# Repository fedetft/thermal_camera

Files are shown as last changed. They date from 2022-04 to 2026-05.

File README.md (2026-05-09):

Thermal camera
===============

An open source thermal camera, including firmware, schematic and PCB design.

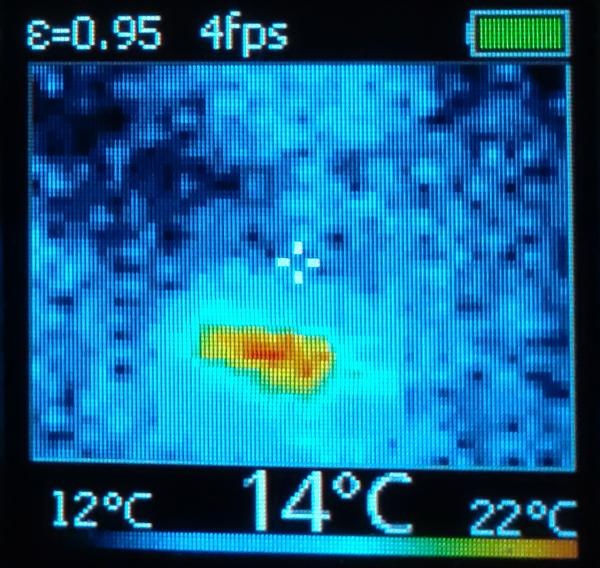
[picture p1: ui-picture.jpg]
UI example

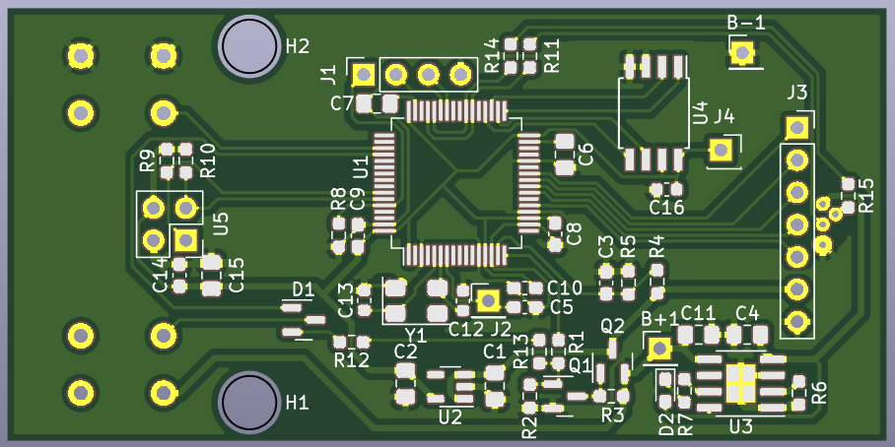
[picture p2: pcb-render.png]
PCB render


How to build
============

This guide assumes you already have a Miosix build environment installed, if not see
[here](https://miosix.org/wiki/index.php?title=Linux_Quick_Start).

```
# Dependencies (should work both on Linux and WSL)
sudo apt install build-essential cmake libboost-all-dev libpng-dev

# Submodules
git submodule init
git submodule update

# Build mxgui code generators for embedding images and fonts
cd mxgui/_tools/code_generators
chmod +x compile_freetype.sh
mkdir build
cd build
cmake ..
make

# Build the thermal camera application
cd ../../../..
make -j`nproc`
```

How to flash
============

Install the dfu-util program on your pc.

Connect the USB cable between the PC an thermal camera, while the camera is off.

Use a jumper wire to connect BOOT0 (on the 4 pin header) to +3.3V (a convenient
spot is a capacitor next to the voltage regulator). You can just hold the wire
with your hands.

While the jumper is in place, press and hold the power on button of the camera.

You can disconnect the jumper but keep holding the power button. If you release
the power button, you need to reconnect the jumper and start again.

On the PC, run the command while holding the power button.
```
dfu-util -a 0 -s 0x08000000:leave -D main.bin
```

You should see a progress bar on the PC, keep holding the power button till the
progress bar reaches 100%.

Release the power button, and disconnect the USB cable.

Power on the camera and enjoy the new firmware. You cannot brick the camera,
if something goes wrong you can repeat the operation.

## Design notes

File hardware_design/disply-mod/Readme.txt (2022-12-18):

Modding the OLED display
========================

The OLED display has a single VCC line that is connected to both
- the display controller chip, maximum voltage 3.6V
- the DC-DC step-up voltage regulator to produce +12V for the OLED panel,
  the DC-DC chip has a maximum input voltage of 5.5V

To optimize the battery life of the thermal camera, those two supply lines have
been split, so as to power the display controller with 3.3V, but connect the
DC-DC directly to the lithium battey voltage (3.5..4.2V).

NOTE: the display mod is mandatory, soldering an unmodded display will drive
the display controller with 4.2V and permanently damage it.

How to mod the OLED display
===========================

See display_mod.jpg

With a knife carefully cut the shown trace to separate the logic power trace
from the DC-DC power trace. Confirm with a multimeter that the trace is cut and
not accidentally shorted to ground (the trace immediately above and below is
ground).

With the same knife or similar tool carefully scrape the soldermask to the
left side of the trace, the one connecting to the display controller chip,
and solder a short piece of flexible copper wire.

Finally, when soldering the display to the thermal camera board, there is a
one-pin connector, J4 where the flexible wire going to the display controller
needs to be soldeered.

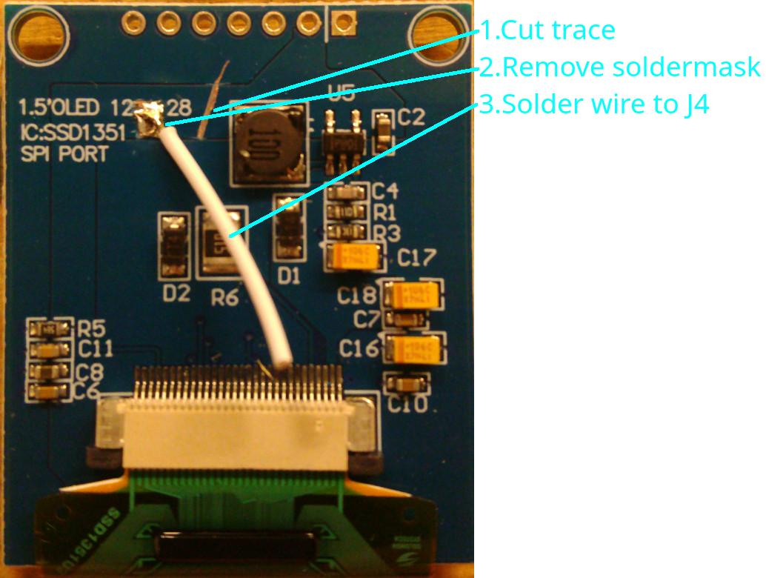
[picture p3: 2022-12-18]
hardware_design/disply-mod/display_mod.jpg

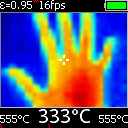
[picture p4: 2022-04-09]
ui-mockup-main-screen.png

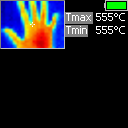
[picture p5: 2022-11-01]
ui-mockup-menu-screen.png

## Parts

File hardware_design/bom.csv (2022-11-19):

Qty | Reference(s) | Value | Footprint
5 | R1, R3, R6, R9, R10 | 3k3 | Resistor_SMD:R_0603_1608Metric
4 | R2, R4, R5, R8 | 220k | Resistor_SMD:R_0603_1608Metric
1 | R7 | 470 | Resistor_SMD:R_0603_1608Metric
5 | R11, R12, R13, R14, R15 | 0 | Resistor_SMD:R_0603_1608Metric
5 | C1, C2, C4, C11, C15 | 1u | Capacitor_SMD:C_0805_2012Metric
7 | C3, C5, C8, C9, C10, C14, C16 | 100n | Capacitor_SMD:C_0603_1608Metric
2 | C6, C7 | 2u2 | Capacitor_SMD:C_0805_2012Metric
2 | C12, C13 | 10p | Capacitor_SMD:C_0603_1608Metric
1 | D1 | BAT54A | SOT-23
1 | D2 | LED | LED_SMD:LED_0603_1608Metric
1 | J1 | 4 pin serial/programming connector | Connector_PinSocket_2.54mm
0 | J2 | Do not fit
1 | J3, J4 | ER_OLEDM015 OLED color 128x128 | https://www.ebay.com/itm/401236987473 NOTE: requires modding to separate DCDC power from logic power, soldering an unmodded display will damage it!
1 | J5 | USB_B_Mini | TE Connectivity:2172034-1
1 | Q1 | AP2312 / SI2312 | SOT-23
1 | Q2 | AP2311 / SI2311 | SOT-23
2 | SW1, SW2 | 1-1825910-4 | SW_PUSH_6mm TE connectivity:1-1825910-4 Mouser:506-1-1825910-4
1 | U1 | STM32F205RC | LQFP-64
1 | U2 | LP2981-3.3 | SOT-23-5
1 | U3 | TP4056 | SOIC-8-1EP
1 | U4 | W25Q64 | SOIC-8W
1 | U5 | MLX90640-BAB | NOTE: Requires bending pins for right angle mount
1 | Y1 | 8MHz | ABRACON ABM3B-8.000MHZ-10-1-U-T
1 | B+1, B-1 | LiPo battery 1Ah | https://www.ebay.com/itm/123867825568

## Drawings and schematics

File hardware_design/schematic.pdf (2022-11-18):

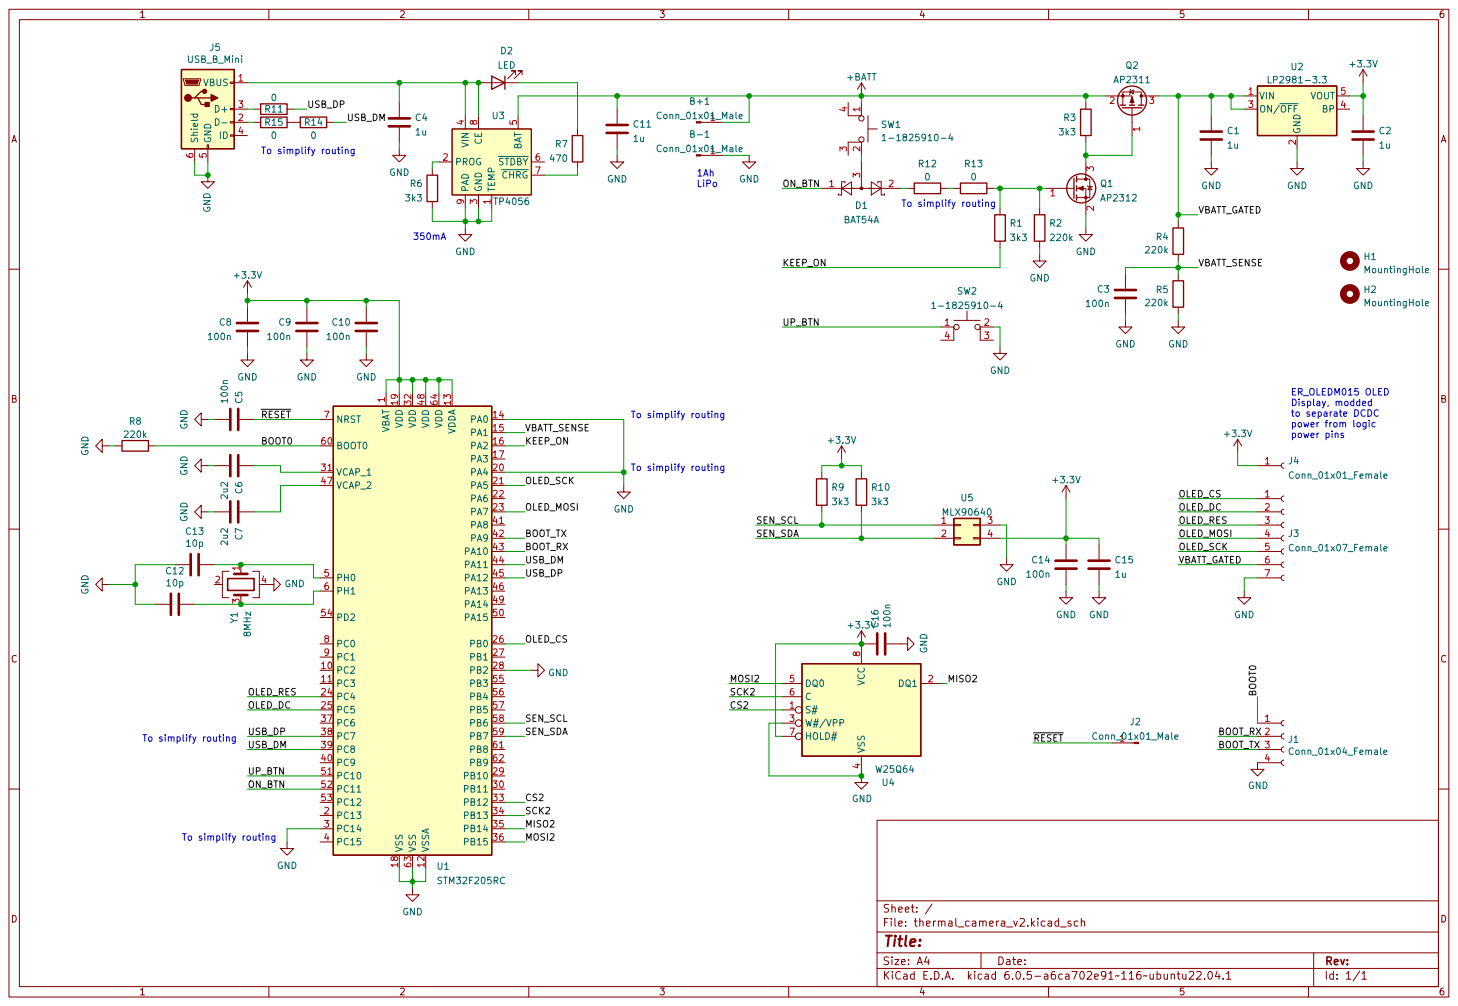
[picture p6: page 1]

2 ON/~{OFF} 3 BP 4 VOUT 5 U2
LP2981-3.3 GND

1 PC2 10 PC3 11 VSSA 12 VDDA 13 PA0 14 PA1 15 PA2 16 PA3 17 VSS 18 VDD 19 PC13 2 PA4 20 PA5 21 PA6 22 PA7 23 PC4 24 PC5 25 PB0 26 PB1 27 PB2 28 PB10 29 PC14 3 PB11 30 VCAP_1 31 VDD 32 PB12 33 PB13 34 PB14 35 PB15 36 PC6 37 PC7 38 PC8 39 PC15 4 PC9 40 PA8 41 PA9 42 PA10 43 PA11 44 PA12 45 PA13 46 VCAP_2 47 VDD 48 PA14 49 PH0 5 PA15 50 PC10 51 PC11 52 PC12 53 PD2 54 PB3 55 PB4 56 PB5 57 PB6 58 PB7 59 PH1 6 BOOT0 60 PB8 61 PB9 62 VSS 63 VDD 64 NRST 7 PC0 8 PC1 9 U1STM32F205RC

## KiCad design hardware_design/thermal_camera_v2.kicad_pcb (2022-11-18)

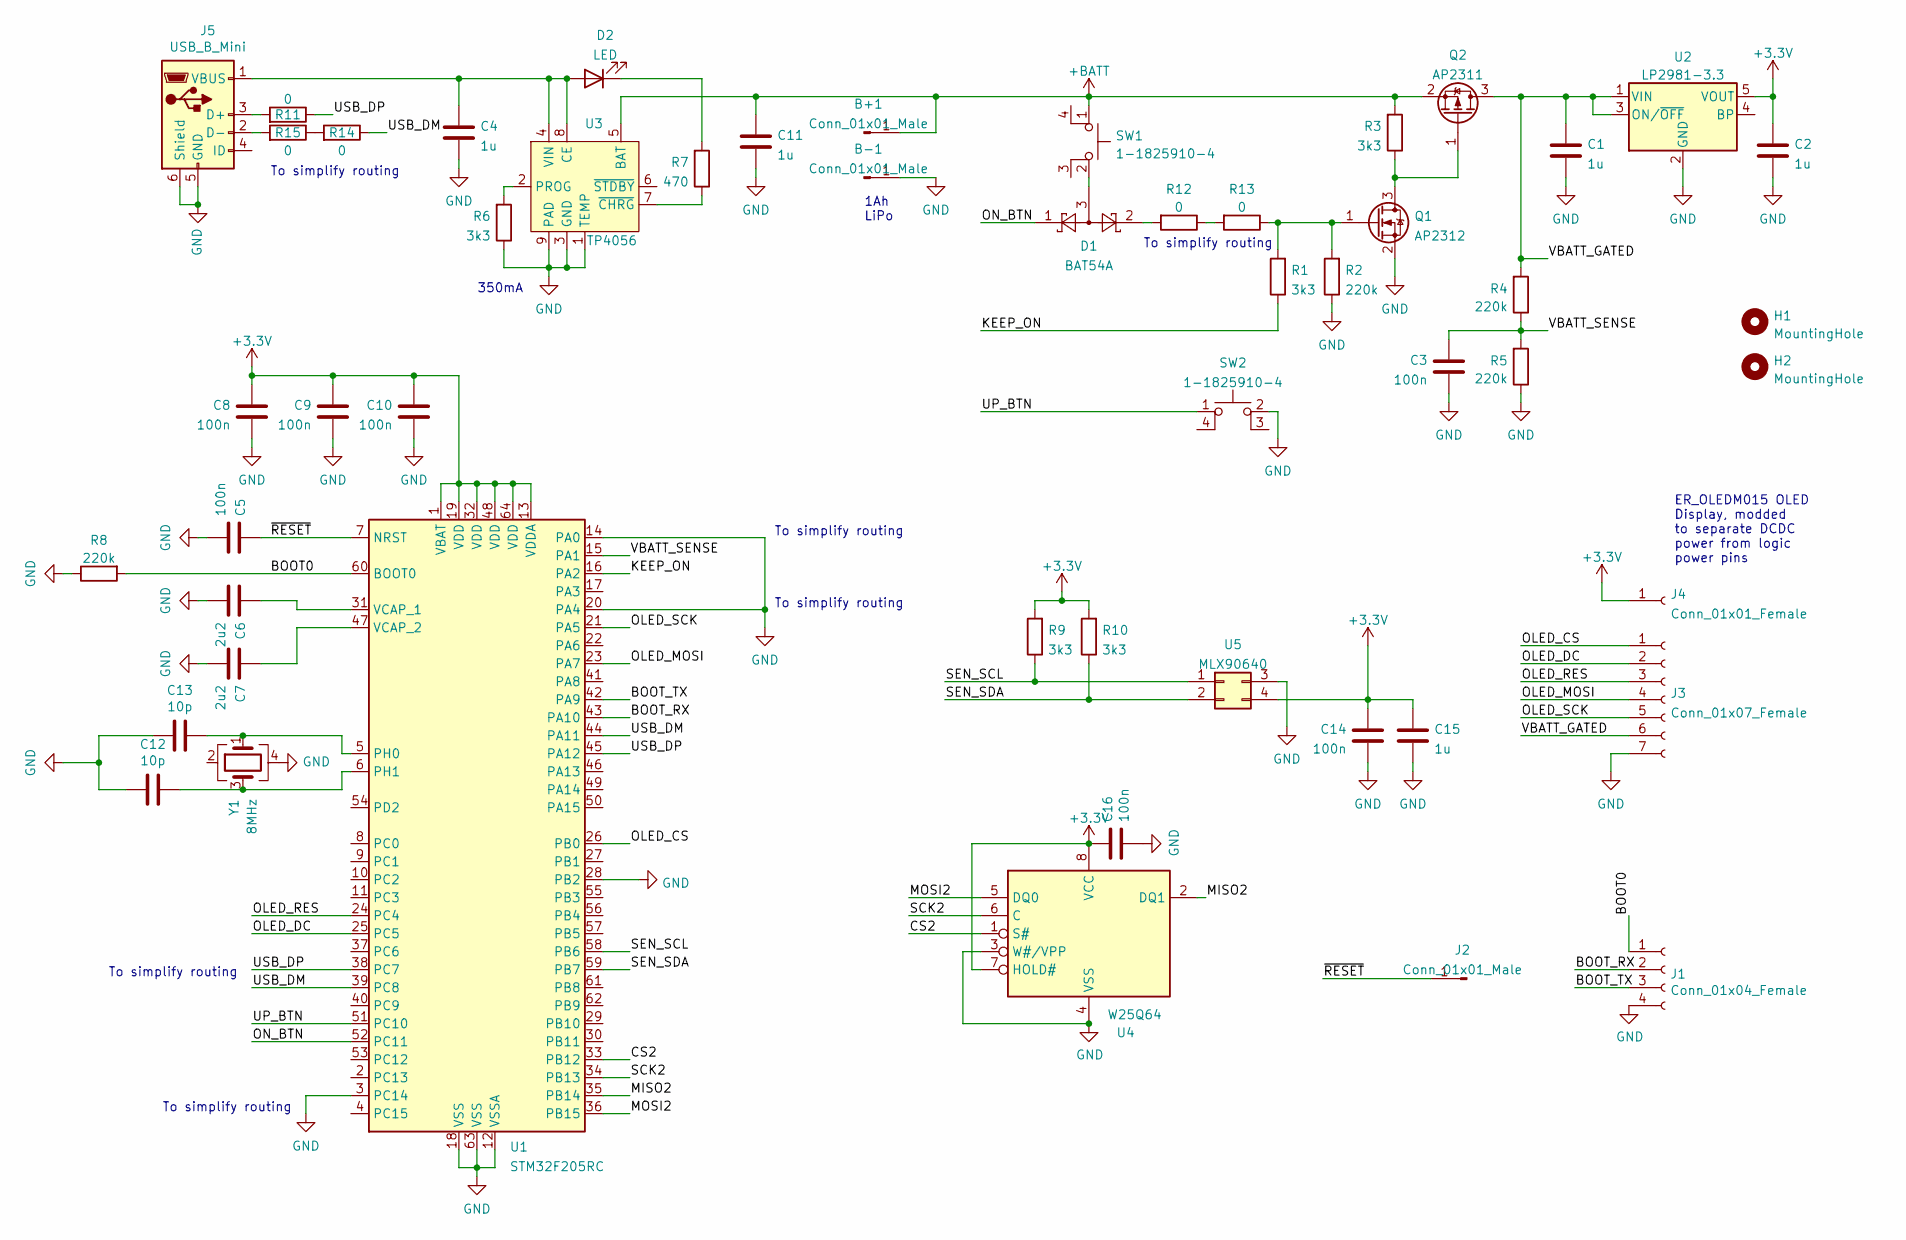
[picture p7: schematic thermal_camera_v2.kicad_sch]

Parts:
B+1: Conn_01x01_Male; PinHeader_1x01_P2.54mm_Vertical
B-1: Conn_01x01_Male; PinHeader_1x01_P2.54mm_Vertical
C1, C2, C4, C11, C15: 1u; C_0805_2012Metric_Pad1.18x1.45mm_HandSolder
C3, C5, C8, C9, C10, C14: 100n; C_0603_1608Metric_Pad1.08x0.95mm_HandSolder
C6, C7: 2u2; C_0805_2012Metric_Pad1.18x1.45mm_HandSolder
C12, C13: 10p; C_0603_1608Metric
C16: 100n; C_0603_1608Metric
D1: BAT54A; SOT-23
D2: LED; LED_0603_1608Metric_Pad1.05x0.95mm_HandSolder
H1, H2: MountingHole; MountingHole_2.1mm
J1: Conn_01x04_Female; PinSocket_1x04_P2.54mm_Vertical
J2: Conn_01x01_Male; PinHeader_1x01_P2.54mm_Vertical
J3: Conn_01x07_Female; PinSocket_1x07_P2.54mm_Vertical
J4: Conn_01x01_Female; PinSocket_1x01_P2.54mm_Vertical
J5: USB_B_Mini; USB_mini_china_unknown
Q1: AP2312; SOT-23
Q2: AP2311; SOT-23
R1, R3, R6, R9, R10: 3k3; R_0603_1608Metric_Pad0.98x0.95mm_HandSolder
R2, R4, R5, R8: 220k; R_0603_1608Metric_Pad0.98x0.95mm_HandSolder
R7: 470; R_0603_1608Metric_Pad0.98x0.95mm_HandSolder
R11, R12, R13, R14, R15: 0; R_0603_1608Metric_Pad0.98x0.95mm_HandSolder
SW1, SW2: 1-1825910-4; SW_PUSH_6mm
U1: STM32F205RC; LQFP-64_10x10mm_P0.5mm
U2: LP2981-3.3; SOT-23-5
U3: TP4056; SOIC-8-1EP_3.9x4.9mm_P1.27mm_EP2.29x3mm
U4: W25Q64; SOIC-8W_5.3x5.3mm_P1.27mm
U5: MLX90640; PinSocket_2x02_P2.54mm_Vertical
Y1: 8MHz; Crystal_SMD_5032-4Pin_5.0x3.2mm

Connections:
+3V3: C2.1, C8.2, C9.2, C10.2, C14.2, C15.1, C16.1, J4.1, R9.2, R10.2, U1.1 (VBAT), U1.13 (VDDA), U1.19 (VDD), U1.32 (VDD), U1.48 (VDD), U1.64 (VDD), U2.5 (VOUT), U4.7 (HOLD#), U4.8 (VCC), U5.4
+BATT: B+1.1, C11.1, Q2.2 (S), R3.2, SW1.1, U3.5 (BAT)
/BOOT0: J1.1, R8.2, U1.60 (BOOT0)
/BOOT_RX: J1.2, U1.43 (PA10)
/BOOT_TX: J1.3, U1.42 (PA9)
/CS2: U1.33 (PB12), U4.1 (S#)
/KEEP_ON: R1.1, U1.16 (PA2)
/MISO2: U1.35 (PB14), U4.2 (DQ1)
/MOSI2: U1.36 (PB15), U4.5 (DQ0)
/OLED_CS: J3.1, U1.26 (PB0)
/OLED_DC: J3.2, U1.25 (PC5)
/OLED_MOSI: J3.4, U1.23 (PA7)
/OLED_RES: J3.3, U1.24 (PC4)
/OLED_SCK: J3.5, U1.21 (PA5)
/ON_BTN: D1.1, U1.52 (PC11)
/SCK2: U1.34 (PB13), U4.6 (C)
/SEN_SCL: R9.1, U1.58 (PB6), U5.1
/SEN_SDA: R10.1, U1.59 (PB7), U5.2
/UP_BTN: SW2.1, U1.51 (PC10)
/USB_DM: R14.1, U1.39 (PC8), U1.44 (PA11)
/USB_DP: R11.1, U1.38 (PC7), U1.45 (PA12)
/VBATT_GATED: C1.1, J3.6, Q2.3 (D), R4.2, U2.1 (VIN), U2.3 (ON/~OFF)
/VBATT_SENSE: C3.2, R4.1, R5.2, U1.15 (PA1)
/~RESET: C5.2, J2.1, U1.7 (NRST)
GND: B-1.1, C1.2, C2.2, C3.1, C4.2, C5.1, C6.2, C7.2, C8.1, C9.1, C10.1, C11.2, C12.2, C13.2, C14.1, C15.2, C16.2, J1.4, J3.7, J5.5 (GND), J5.6 (Shield), Q1.2 (S), R2.1, R5.1, R6.1, R8.1, SW2.2, U1.3 (PC14), U1.12 (VSSA), U1.14 (PA0), U1.18 (VSS), U1.20 (PA4), U1.28 (PB2), U1.63 (VSS), U2.2 (GND), U3.1 (TEMP), U3.3 (GND), U3.9 (PAD), U4.3 (W#/VPP), U4.4 (VSS), U5.3, Y1.4
unnamed: C4.1, D2.2 (A), J5.1 (VBUS), U3.4 (VIN), U3.8 (CE)
unnamed: C6.1, U1.31 (VCAP_1)
unnamed: C7.1, U1.47 (VCAP_2)
unnamed: C12.1, U1.6 (PH1), Y1.3
unnamed: C13.1, U1.5 (PH0), Y1.1
unnamed: D1.2, R12.2
unnamed: D1.3, SW1.2
unnamed: D2.1 (K), R7.2
unnamed: J5.2 (D-), R15.2
unnamed: J5.3 (D+), R11.2
unnamed: Q1.1 (G), R1.2, R2.2, R13.1
unnamed: Q1.3 (D), Q2.1 (G), R3.1
unnamed: R6.2, U3.2 (PROG)
unnamed: R7.1, U3.7 (~CHRG)
unnamed: R12.1, R13.2
unnamed: R14.2, R15.1

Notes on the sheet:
To simplify routing
ER_OLEDM015 OLED Display, modded to separate DCDC power from logic power pins
350mA
1Ah LiPo

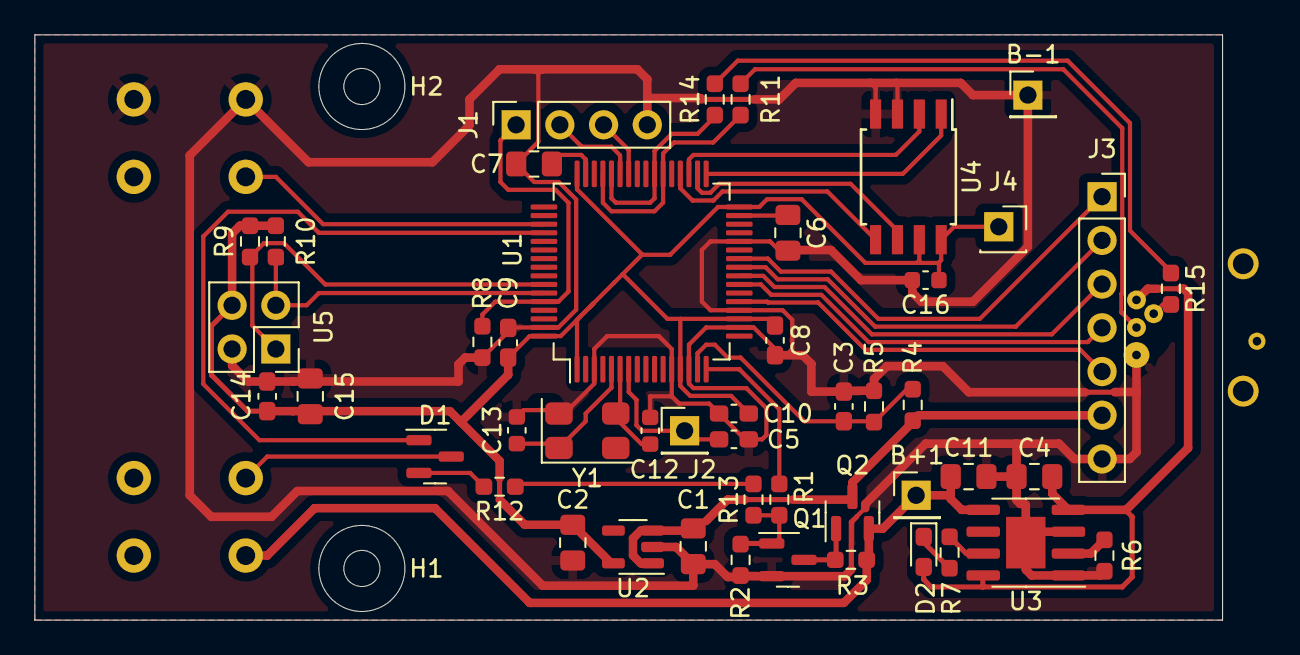
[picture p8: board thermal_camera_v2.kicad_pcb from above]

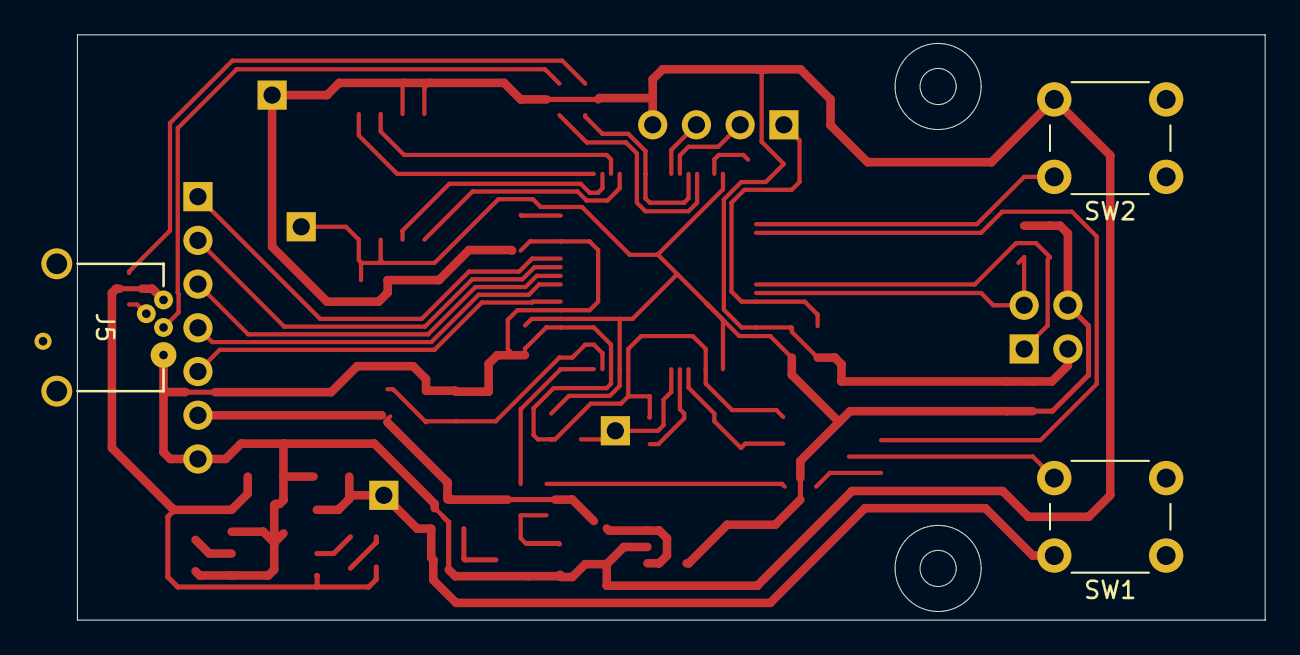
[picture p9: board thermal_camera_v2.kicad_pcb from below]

Board: 2 copper layers, 69.0 x 34.0 mm, 52 parts (3 on the bottom side), 41 nets.

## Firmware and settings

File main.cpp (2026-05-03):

/***************************************************************************
 *   Copyright (C) 2022 by Terraneo Federico                               *
 *                                                                         *
 *   This program is free software; you can redistribute it and/or modify  *
 *   it under the terms of the GNU General Public License as published by  *
 *   the Free Software Foundation; either version 2 of the License, or     *
 *   (at your option) any later version.                                   *
 *                                                                         *
 *   This program is distributed in the hope that it will be useful,       *
 *   but WITHOUT ANY WARRANTY; without even the implied warranty of        *
 *   MERCHANTABILITY or FITNESS FOR A PARTICULAR PURPOSE.  See the         *
 *   GNU General Public License for more details.                          *
 *                                                                         *
 *   As a special exception, if other files instantiate templates or use   *
 *   macros or inline functions from this file, or you compile this file   *
 *   and link it with other works to produce a work based on this file,    *
 *   this file does not by itself cause the resulting work to be covered   *
 *   by the GNU General Public License. However the source code for this   *
 *   file must still be made available in accordance with the GNU General  *
 *   Public License. This exception does not invalidate any other reasons  *
 *   why a work based on this file might be covered by the GNU General     *
 *   Public License.                                                       *
 *                                                                         *
 *   You should have received a copy of the GNU General Public License     *
 *   along with this program; if not, see <http://www.gnu.org/licenses/>   *
 ***************************************************************************/

#include <cstdio>
#include "miosix.h"
#include <drivers/misc.h>
#include <application.h>
#include <mxgui/display.h>
#include <drivers/display_er_oledm015.h>

using namespace std;
using namespace mxgui;
using namespace miosix;

namespace mxgui {
void registerDisplayHook(DisplayManager& dm)
{
    dm.registerDisplay(new DisplayErOledm015);
}
} //namespace mxgui

#ifdef WITH_CPU_TIME_COUNTER
void *profilerMain(void *)
{
    CPUProfiler::thread(5000000000LL);
    return nullptr;
}
#endif

int main()
{
    initializeBoard();
    
    #ifdef WITH_CPU_TIME_COUNTER
    Thread *profiler = Thread::create(profilerMain, 2048U, Priority(0), nullptr);
    #endif

    auto& display=DisplayManager::instance().getDisplay();
    
    try {
        Application app(display);
        app.run();
    } catch(exception& e) {
        iprintf("exception: %s\n",e.what());
    }
    
    display.turnOff();
    #ifdef WITH_CPU_TIME_COUNTER
    profiler->terminate();
    profiler->join();
    #endif
    shutdownBoard();
}

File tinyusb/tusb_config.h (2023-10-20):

#ifndef _TUSB_CONFIG_H_
#define _TUSB_CONFIG_H_

#ifdef __cplusplus
 extern "C" {
#endif

//--------------------------------------------------------------------+
// Board Specific Configuration
//--------------------------------------------------------------------+

// RHPort number used for device can be defined by board.mk, default to port 0
#ifndef BOARD_TUD_RHPORT
#define BOARD_TUD_RHPORT      0
#endif

// RHPort max operational speed can defined by board.mk
#ifndef BOARD_TUD_MAX_SPEED
#define BOARD_TUD_MAX_SPEED   OPT_MODE_DEFAULT_SPEED
#endif

//--------------------------------------------------------------------
// Common Configuration
//--------------------------------------------------------------------

// defined by compiler flags for flexibility
#ifndef CFG_TUSB_MCU
#define CFG_TUSB_MCU          OPT_MCU_STM32F2
#endif

#ifndef CFG_TUSB_OS
#define CFG_TUSB_OS           OPT_OS_CUSTOM
#endif

#ifndef CFG_TUSB_DEBUG
#define CFG_TUSB_DEBUG        1
#endif

// Enable Device stack
#define CFG_TUD_ENABLED       1

// Default is max speed that hardware controller could support with on-chip PHY
#define CFG_TUD_MAX_SPEED     BOARD_TUD_MAX_SPEED

/* USB DMA on some MCUs can only access a specific SRAM region with restriction on alignment.
 * Tinyusb use follows macros to declare transferring memory so that they can be put
 * into those specific section.
 * e.g
 * - CFG_TUSB_MEM SECTION : __attribute__ (( section(".usb_ram") ))
 * - CFG_TUSB_MEM_ALIGN   : __attribute__ ((aligned(4)))
 */
#ifndef CFG_TUSB_MEM_SECTION
#define CFG_TUSB_MEM_SECTION
#endif

#ifndef CFG_TUSB_MEM_ALIGN
#define CFG_TUSB_MEM_ALIGN    __attribute__ ((aligned(4)))
#endif

//--------------------------------------------------------------------
// DEVICE CONFIGURATION
//--------------------------------------------------------------------

#ifndef CFG_TUD_ENDPOINT0_SIZE
#define CFG_TUD_ENDPOINT0_SIZE    64
#endif

//------------- CLASS -------------//
#define CFG_TUD_CDC              1
#define CFG_TUD_MSC              0
#define CFG_TUD_HID              0
#define CFG_TUD_MIDI             0
#define CFG_TUD_VENDOR           0

// CDC FIFO size of TX and RX
#define CFG_TUD_CDC_RX_BUFSIZE   (TUD_OPT_HIGH_SPEED ? 512 : 64)
#define CFG_TUD_CDC_TX_BUFSIZE   (TUD_OPT_HIGH_SPEED ? 512 : 64)

// CDC Endpoint transfer buffer size, more is faster
#define CFG_TUD_CDC_EP_BUFSIZE   (TUD_OPT_HIGH_SPEED ? 512 : 64)

#define CFG_TUSB_RHPORT0_MODE (OPT_MODE_DEVICE)
#define CFG_TUSB_RHPORT1_MODE (OPT_MODE_NONE)

#ifdef __cplusplus
 }
#endif

#endif /* _TUSB_CONFIG_H_ */

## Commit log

2022-03-21 After a long time, first hardware I2C working, still needs cleanup
2022-03-27 Adapting to updated I2C driver
2022-03-27 Use new sendRecv of I2C driver and simplify code
2022-04-03 Improved MLX90640 algorithms to never use double (30% speed improvement), added thread-able mlx90640 driver to read sensor code, refacored application to use threads, max speed for now 4Hz
2022-04-03 Optimized display draw to a single image draw call, that made 8fps possible also without DMA
2022-04-05 First version of DMA-accelerated display image drawing
2022-04-05 Logo and battery icon
2022-04-06 Added colormap encoder
2022-04-09 Main frame of the UI completed
2022-04-09 optimized scanLine with DMA, faster serial port
2022-04-09 Short mode, made rendering 6x faster but at a loss of image quality
    [application.cpp, mlx90640.cpp]
2022-04-10 Now with more comments! And better error code paths too!
    [application.cpp, main.cpp, mlx90640.cpp]
2022-11-04 Decoupled UI loop from sensor refresh to prevent slow UI at slow fps
    [application.cpp]
2022-11-06 Added Kicad pcb files
    [thermal_camera_v2.kicad_pcb, thermal_camera_v2.kicad_sch]
2022-11-18 Fix button part number, add components BOM
    [bom.csv, thermal_camera_v2.kicad_pcb, thermal_camera_v2.kicad_sch]
2022-11-18 Switched XTAL footprint
    [bom.csv, thermal_camera_v2.kicad_pcb, thermal_camera_v2.kicad_sch]
2022-11-19 Specified full sensor part number
    [bom.csv]
2022-12-26 mlx90640 driver: Sleep for 80ms before attempting to read the EEPROM.
2022-12-26 Update gitignore to include KiCad temporary files.
2023-02-08 Added interactive bill of material
2023-02-21 Improve menu UI flow.
2023-02-21 Update the battery icon from ApplicationUI.
2023-02-21 Turn off board only with a long press of the on button.
2023-02-21 Add a feature for pausing acquisition by pressing the ON/OFF button.
2023-02-21 Add a secret feature for displaying the Miosix version when the up button is pressed at boot.
2023-02-21 Fix button state initializer.
    [application.cpp]
2023-02-21 Also print the version number from git together with the Miosix version in the secret screen.
2023-02-21 Fix a bug where shutdown would deadlock if acquisition is paused.
    [application.cpp, applicationui.h]
2023-02-21 Use Miosix threads instead of std::thread.
    The main motivation is to get rid of the redundancy between the sensorThreadId attribute and the st local inside Application::run().
    We were already using Miosix-specific priority features so this also ends up cleaning the code further.
2023-02-21 Move the colormap encoder into _tools.
2023-03-14 Optimize the sensor processing code by using fast inverse square root and better compilation options.
2023-03-16 Properly put the current thread to sleep when waiting for SPI DMA rather than polling almost all the time.
2023-05-27 Add a missing call to setTextColor.
    [applicationui.h]
2023-10-15 Add USB CDC driver class implemented as a frontend for tinyUSB.
2023-10-15 Add function for retrieving MLX90640 EEPROM contents even after device initialization.
2023-10-15 Add USB communication threads and the ability to stream frames in real time.
2023-10-15 Do not lock up when reads to the I2C bus repeatedly fail.
    [mlx90640.cpp]
2023-10-15 Remove unused original Melexis I2C code.
2023-10-15 Move frame processing code out of the MLX90640 driver.
2023-10-15 Simulator: add support for getting frames from other sources
2023-10-15 Add the ability to stream images from a physical device in the simulator.
2023-11-06 Fix a deadlock issue that could manifest when exiting the menu.
    The lastFrameMutex was held when drawing a frame, which could cause a deadlock when the render thread attempts to draw a frame while the main thread is already drawing the UI. The render thread cannot proceed in updateFrame and call drawFrame because the DrawingContext mutex is locked, but the main UI cannot proceed inside drawFrame itself because the render thread has already locked the lastFrameMutex.
    The fix changes lastFrameMutex to only protect the actual modifications to lastFrame.
    [applicationui.h]
2026-05-03 Update application and drivers to Miosix 3
